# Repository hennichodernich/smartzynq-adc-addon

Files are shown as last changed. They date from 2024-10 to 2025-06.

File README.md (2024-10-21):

# smartzynq-adc-addon
KiCad files for the SmartZynq ADC addon board

*Make sure to reconfigure VCCIO on the SmartZynq to 2.5V!*

Licensed under CERN-OHL-W v2

## Hardware build

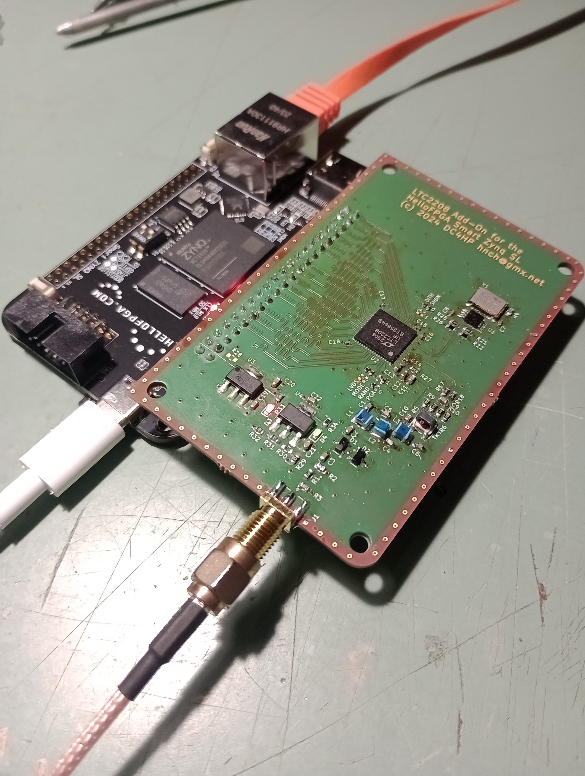
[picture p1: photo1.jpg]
The addon board mounted on the FPGA board


This board is supposed to be mounted on a HelloFPGA Smart Zynq SL FPGA board such as the one that can be purchased [here](https://aliexpress.com/item/1005006384235496.html).

It can be nicely mounted in an enclosure such as [this one](https://aliexpress.com/item/1005007125132369.html):

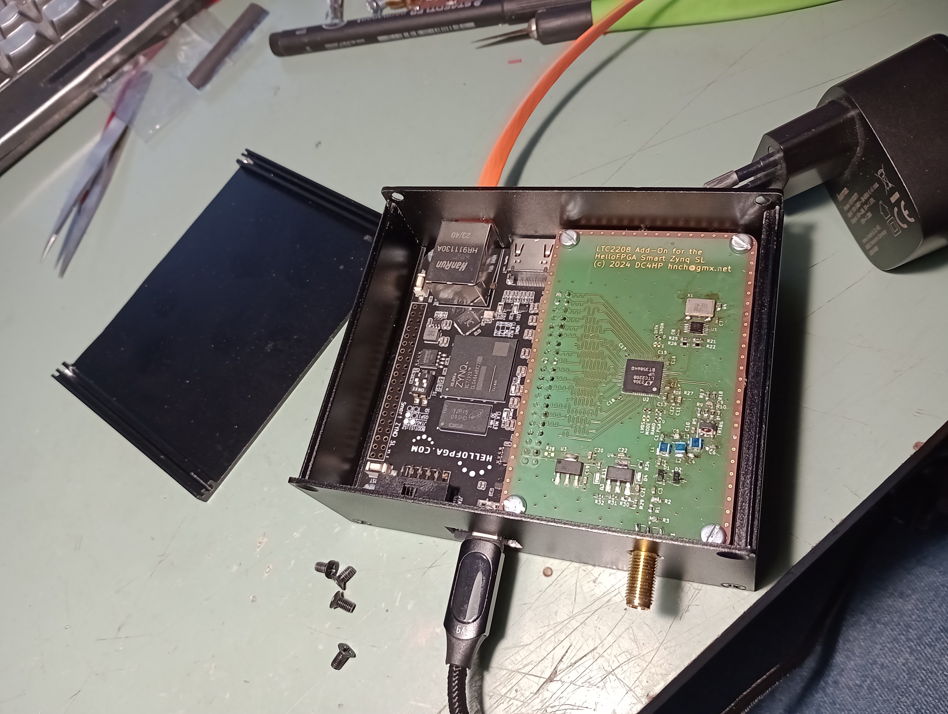
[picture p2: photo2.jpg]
Board stack mounted in enclosure


## Receive performance

The receive performance of the [sdr_receiver_ft8_122_88 project](https://github.com/hennichodernich/hellofpga-smartzynq-notes/tree/main/projects/sdr_receiver_ft8_122_88) is really good (on 22m EFHW):

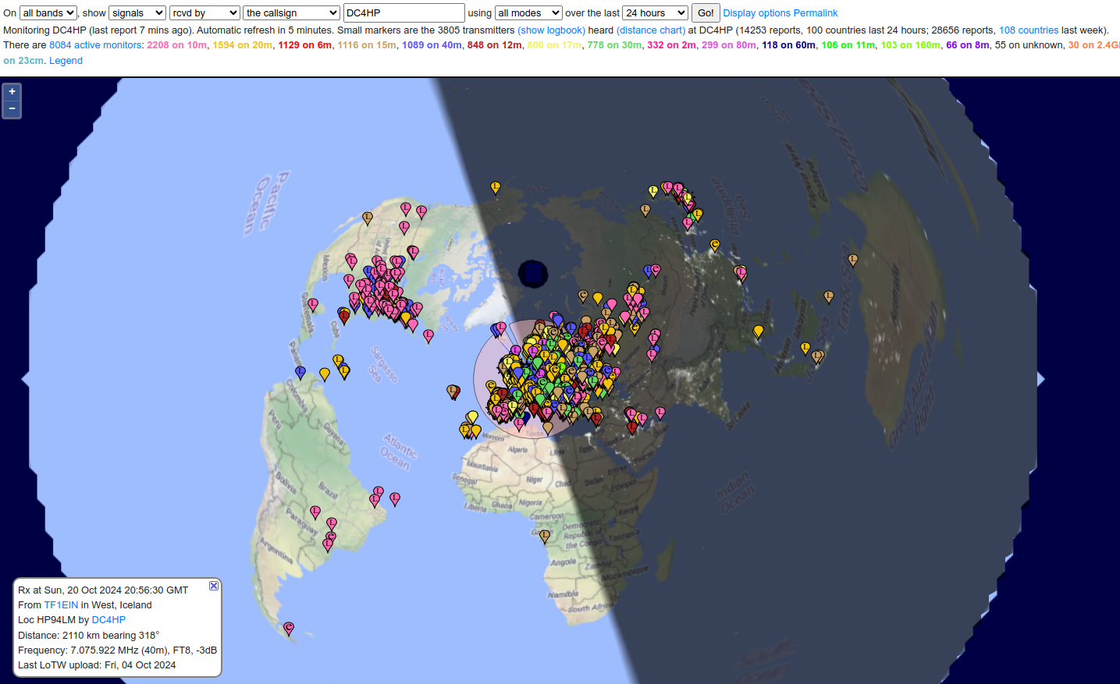
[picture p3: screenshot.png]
PSK Reporter screenshot


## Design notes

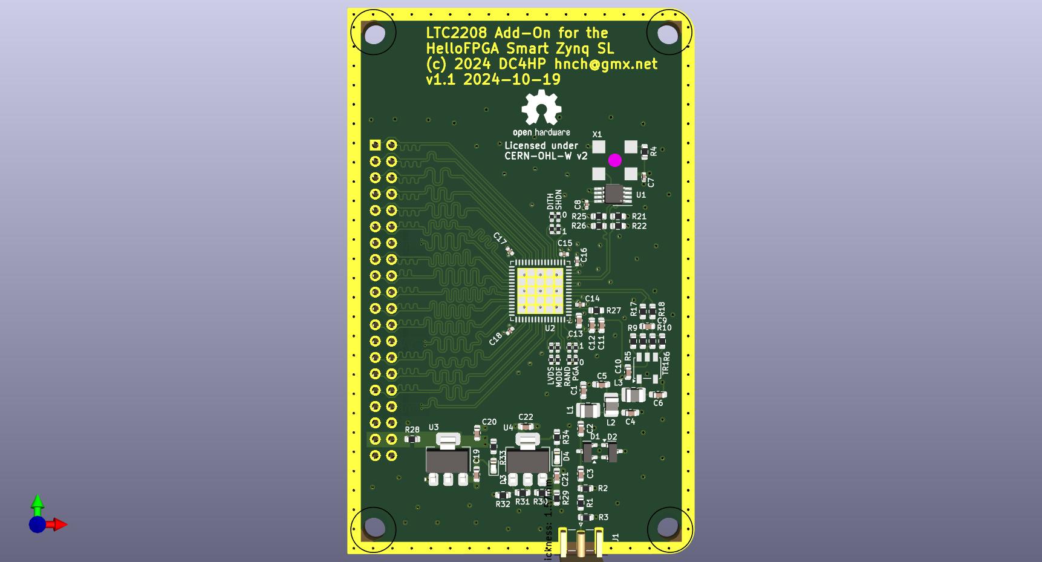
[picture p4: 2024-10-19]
kicad/ltc2208-adc.jpg

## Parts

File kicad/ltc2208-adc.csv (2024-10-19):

Reference | Value | Datasheet | Footprint | Qty | DNP
C1,C6 | 120p | ~ | hnch:C_0603_0402_HandSolder_Combo | 2
C2,C3 | 1u | ~ | Capacitor_SMD:C_0603_1608Metric | 2
C4,C5 | 220p | ~ | hnch:C_0603_0402_HandSolder_Combo | 2
C7,C8,C14,C15,C16,C17,C18 | 100n | ~ | Capacitor_SMD:C_0402_1005Metric | 7
C9 | 4.7p | ~ | Capacitor_SMD:C_0603_1608Metric | 1
C10,C11 | 10n | ~ | Capacitor_SMD:C_0603_1608Metric | 2
C12,C13,C19,C20,C21,C22 | 2.2u | ~ | Capacitor_SMD:C_0603_1608Metric | 6
D1,D2 | BAV99 | https://assets.nexperia.com/documents/data-sheet/BAV99_SER.pdf | Package_TO_SOT_SMD:SOT-23 | 2
D3,D4 | LED | ~ | LED_SMD:LED_0603_1608Metric | 2
J1 | Conn_Coaxial | ~ | Connector_Coaxial:SMA_Samtec_SMA-J-P-H-ST-EM1_EdgeMount | 1
J2 | Conn_02x20_Odd_Even | ~ | Connector_PinSocket_2.54mm:PinSocket_2x20_P2.54mm_Vertical | 1
L1,L2,L3 | 390nH | ~ | hnch:L_1008_0805_0603_HandSolder_Combo | 3
R1 | 5.1 | ~ | Resistor_SMD:R_0603_1608Metric | 1
R2,R3 | 1k | ~ | Resistor_SMD:R_0603_1608Metric | 2
R4,R7,R12,R13,R16,R20,R23 | 4.7k | ~ | -- verschiedene Werte -- | 7
R5,R6,R17,R18 | 10 | ~ | Resistor_SMD:R_0603_1608Metric | 4
R8,R11,R14,R15,R19,R24,R28,R30 | np | ~ | -- verschiedene Werte -- | 8
R9,R10 | 33.2 | ~ | Resistor_SMD:R_0603_1608Metric | 2
R21,R25 | 130 | ~ | Resistor_SMD:R_0603_1608Metric | 2
R22,R26 | 83 | ~ | Resistor_SMD:R_0603_1608Metric | 2
R27 | 100 | ~ | Resistor_SMD:R_0603_1608Metric | 1
R29 | 0 | ~ | Resistor_SMD:R_0603_1608Metric | 1
R31,R32 | 121 | ~ | Resistor_SMD:R_0603_1608Metric | 2
R33,R34 | 470 | ~ | Resistor_SMD:R_0603_1608Metric | 2
TR1 | ETC4-1-2 | https://cdn.macom.com/datasheets/ETC4-1-2-TR.pdf | Transformer_SMD:Transformer_MACOM_SM-22 | 1
U1 | SN65EPT22 | https://www.ti.com/lit/ds/symlink/sn65ept22.pdf | Package_SO:VSSOP-8_3.0x3.0mm_P0.65mm | 1
U2 | LTC2208 | https://www.analog.com/media/en/technical-documentation/data-sheets/2208fb.pdf | Package_DFN_QFN:QFN-64-1EP_9x9mm_P0.5mm_EP7.15x7.15mm | 1
U3 | LT1117-3.3 | https://www.analog.com/media/en/technical-documentation/data-sheets/1117fd.pdf | Package_TO_SOT_SMD:SOT-223-3_TabPin2 | 1
U4 | LT1117-ADJ | https://www.analog.com/media/en/technical-documentation/data-sheets/1117fd.pdf | Package_TO_SOT_SMD:SOT-223-3_TabPin2 | 1
X1 | 122.88 MHz | http://cdn-reichelt.de/documents/datenblatt/B400/XO91.pdf | Oscillator:Oscillator_SMD_EuroQuartz_XO91-4Pin_7.0x5.0mm | 1

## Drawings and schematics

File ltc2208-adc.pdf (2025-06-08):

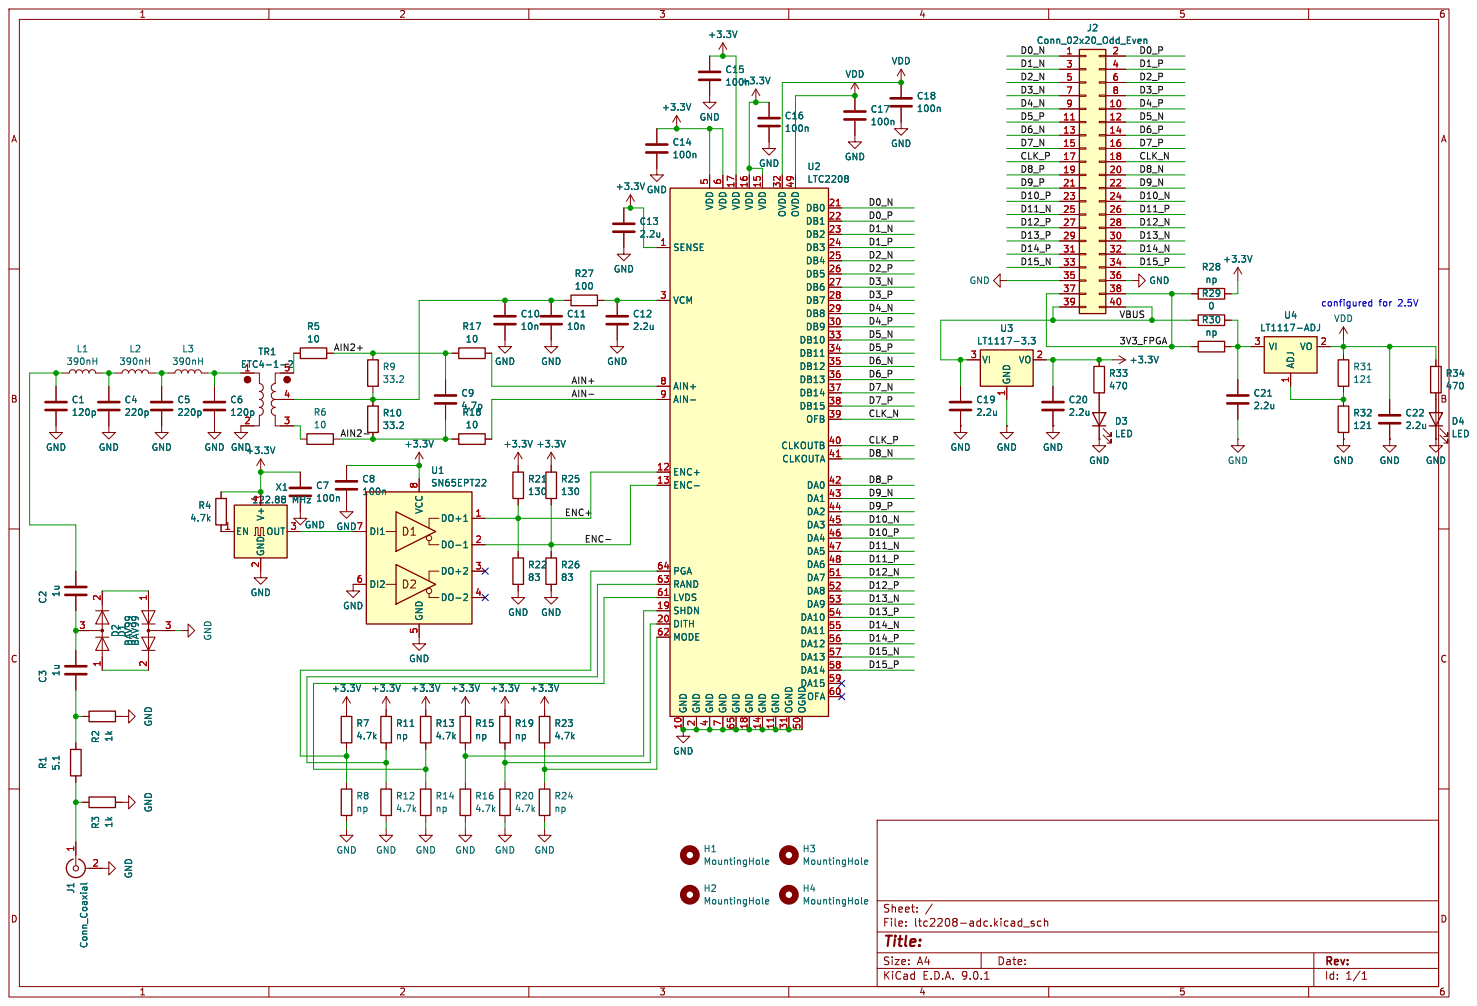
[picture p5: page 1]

7 VDD 16 VDD 15 GND 14 GND 11 OFB 39 SENSE 1 VCM 3 AIN+ 8 AIN- 9 ENC+ 12 ENC- 13 PGA 64 RAND 63 SHDN 19 DITH 20 MODE 62 VDD

6 VDD 17 GND 65 GND 18 OVDD 32 OGND 31 OVDD 49 OGND 50 DB0 21 DB1 22 DB2 23 DB3 24 DB4 25 DB5 26 DB6 27 DB7 28 DB8 29 DB9 30 DB10 33 DB11 34 DB12 35 DB13 36 DB14 37 DB15 38 CLKOUTB 40 CLKOUTA 41 DA0 42 DA1 43 DA2 44 DA3 45 DA4 46 DA5 47 DA6 48 DA7 51 DA8 52 DA9 53 DA10 54 DA11 55 DA12 56 DA13 57 DA14 58 DA15 59 OFA 60 GND

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

5 DO+1 1 DO-1 2 DO+2 3 DO-2 4 U1SN65EPT22 +3.3V C13

2 R31k J1 Conn_Coaxial 1
Id: 1/1 Title: File: ltc2208-adc.kicad_sch Sheet: / C31u

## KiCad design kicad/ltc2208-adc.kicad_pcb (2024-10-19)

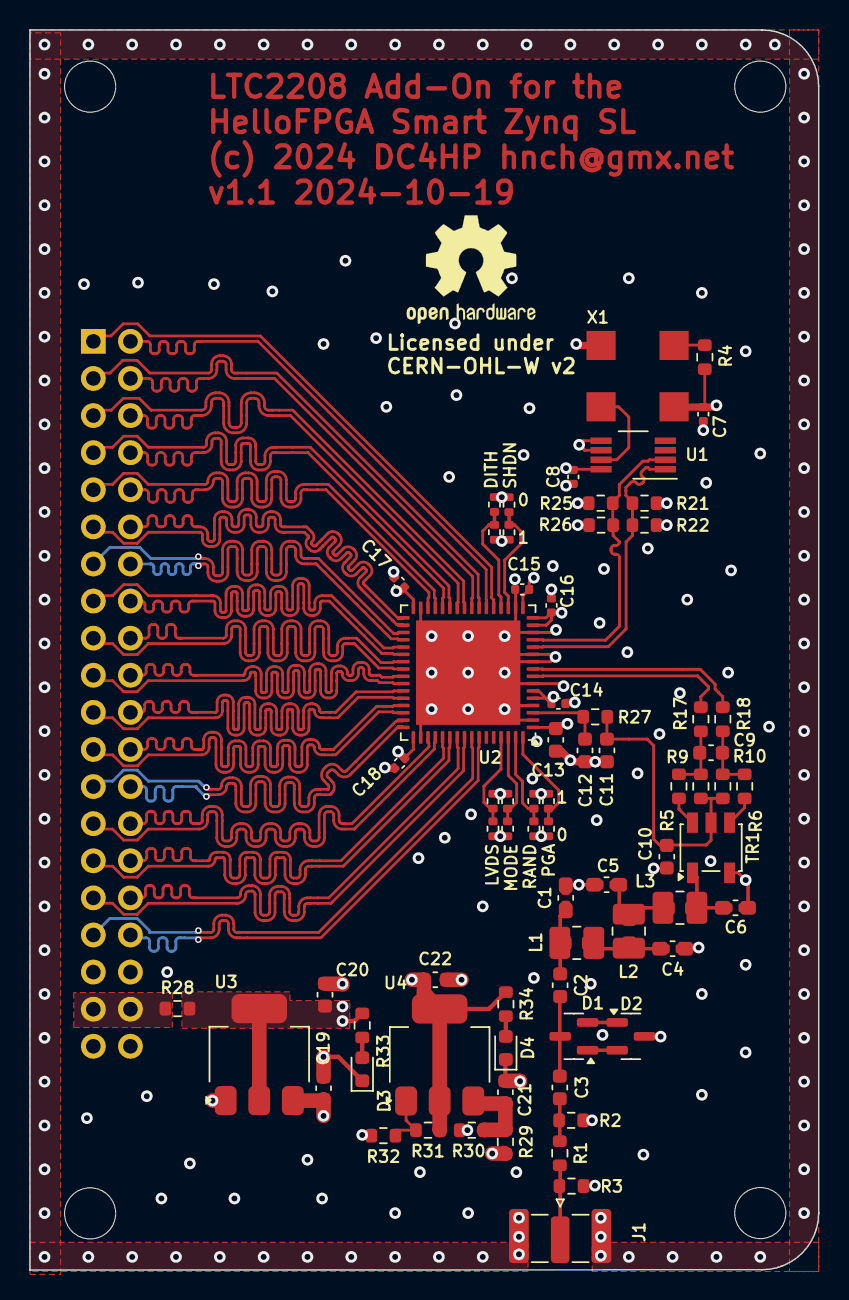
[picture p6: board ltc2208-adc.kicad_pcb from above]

Board: 4 copper layers, 54.0 x 84.9 mm, 75 parts (1 on the bottom side), 70 nets.

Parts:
C1, C4, C5, C6: C; C_0603_0402_HandSolder_Combo
C2, C3: 1u; C_0603_1608Metric
C7, C8, C14, C15, C16, C17, C18: 100n; C_0402_1005Metric
C9: 4.7p; C_0603_1608Metric
C10, C11: 10n; C_0603_1608Metric
C12, C13, C19, C20, C21, C22: 2.2u; C_0603_1608Metric
D1, D2: BAV99; SOT-23
D3, D4: LED; LED_0603_1608Metric
H1, H2, H3, H4: MountingHole; MountingHole_3.5mm
J1: Conn_Coaxial; SMA_Samtec_SMA-J-P-H-ST-EM1_EdgeMount
J2: Conn_02x20_Odd_Even; PinSocket_2x20_P2.54mm_Vertical
L1, L2, L3: L; L_1008_0805_0603_HandSolder_Combo
R1: 5.1; R_0603_1608Metric
R2, R3: 1k; R_0603_1608Metric
R4: 4.7k; R_0603_1608Metric
R5, R6, R17, R18: 10; R_0603_1608Metric
R7, R8, R11, R12, R13, R14, R15, R16, R19, R20, R23, R24: 4.7k; R_0402_1005Metric
R9, R10: 33.2; R_0603_1608Metric
R21, R25: 130; R_0603_1608Metric
R22, R26: 83; R_0603_1608Metric
R27: 100; R_0603_1608Metric
R28, R29, R30: 0; R_0603_1608Metric
R31, R32: R; R_0603_1608Metric
R33, R34: 470; R_0603_1608Metric
TR1: ETC4-1-2; Transformer_MACOM_SM-22
U1: SN65EPT22; VSSOP-8_3.0x3.0mm_P0.65mm
U2: LTC2208; QFN-64-1EP_9x9mm_P0.5mm_EP7.15x7.15mm
U3: LT1117-3.3; SOT-223-3_TabPin2
U4: LT1117-ADJ; SOT-223-3_TabPin2
X1: XO91; Oscillator_SMD_EuroQuartz_XO91-4Pin_7.0x5.0mm

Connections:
+3.3V: C7.1, C8.1, C13.1, C14.1, C15.1, C16.1, C20.1, R4.1, R7.1, R11.1, R13.1, R15.1, R19.1, R21.1, R23.1, R25.1, R28.2, R33.1, U1.8 (VCC), U2.1 (SENSE), U2.5 (VDD), U2.6 (VDD), U2.15 (VDD), U2.16 (VDD), U2.17 (VDD), U3.2 (VO), X1.4 (V+)
/3V3_FPGA: J2.37, J2.38, R28.1, R30.1
/AIN2+: C9.1, R5.2, R9.1, R17.1
/AIN2-: C9.2, R6.2, R10.2, R18.1
/AIN+: R17.2, U2.8 (AIN+)
/AIN-: R18.2, U2.9 (AIN-)
/CLK_N: J2.18, U2.39 (OFB)
/CLK_P: J2.17, U2.40 (CLKOUTB)
/D0_N: J2.1, U2.21 (DB0)
/D0_P: J2.2, U2.22 (DB1)
/D1_N: J2.3, U2.23 (DB2)
/D1_P: J2.4, U2.24 (DB3)
/D2_N: J2.5, U2.25 (DB4)
/D2_P: J2.6, U2.26 (DB5)
/D3_N: J2.7, U2.27 (DB6)
/D3_P: J2.8, U2.28 (DB7)
/D4_N: J2.9, U2.29 (DB8)
/D4_P: J2.10, U2.30 (DB9)
/D5_N: J2.12, U2.33 (DB10)
/D5_P: J2.11, U2.34 (DB11)
/D6_N: J2.13, U2.35 (DB12)
/D6_P: J2.14, U2.36 (DB13)
/D7_N: J2.15, U2.37 (DB14)
/D7_P: J2.16, U2.38 (DB15)
/D8_N: J2.20, U2.41 (CLKOUTA)
/D8_P: J2.19, U2.42 (DA0)
/D9_N: J2.22, U2.43 (DA1)
/D9_P: J2.21, U2.44 (DA2)
/D10_N: J2.24, U2.45 (DA3)
/D10_P: J2.23, U2.46 (DA4)
/D11_N: J2.25, U2.47 (DA5)
/D11_P: J2.26, U2.48 (DA6)
/D12_N: J2.28, U2.51 (DA7)
/D12_P: J2.27, U2.52 (DA8)
/D13_N: J2.30, U2.53 (DA9)
/D13_P: J2.29, U2.54 (DA10)
/D14_N: J2.32, U2.55 (DA11)
/D14_P: J2.31, U2.56 (DA12)
/D15_N: J2.33, U2.57 (DA13)
/D15_P: J2.34, U2.58 (DA14)
/ENC+: R21.2, R22.1, U1.1 (DO+1), U2.12 (ENC+)
/ENC-: R25.2, R26.1, U1.2 (DO-1), U2.13 (ENC-)
/VBUS: C19.1, J2.39, J2.40, R29.1, U3.3 (VI)
GND: C1.2, C4.2, C5.2, C6.2, C7.2, C8.2, C10.2, C11.2, C12.2, C13.2, C14.2, C15.2, C16.2, C17.2, C18.2, C19.2, C20.2, C21.2, C22.2, D2.3 (K), D3.1 (K), D4.1 (K), J1.2 (Ext), J2.35, J2.36, R2.2, R3.2, R8.2, R12.2, R14.2, R16.2, R20.2, R22.2, R24.2, R26.2, R32.2, TR1.2, U1.5 (GND), U1.6 (DI2), U2.2 (GND), U2.4 (GND), U2.7 (GND), U2.10 (GND), U2.11 (GND), U2.14 (GND), U2.18 (GND), U2.31 (OGND), U2.50 (OGND), U2.65 (GND), U3.1 (GND), X1.2 (GND)
unnamed: C1.1, C2.1, L1.1
unnamed: C2.2, C3.1, D1.3 (K)
unnamed: C3.2, R1.1, R2.1
unnamed: C4.1, L1.2, L2.1
unnamed: C5.1, L2.2, L3.1
unnamed: C6.1, L3.2, TR1.1
unnamed: C10.1, C11.1, R9.2, R10.1, R27.1, TR1.4
unnamed: D1.2 (A), D2.1 (K)
unnamed: D1.1 (K), D2.2 (A)
unnamed: D3.2 (A), R33.2
unnamed: D4.2 (A), R34.2
unnamed: J1.1 (In), R1.2, R3.1
unnamed: R5.1, TR1.5
unnamed: R6.1, TR1.3
unnamed: U1.7 (DI1), X1.3 (OUT)
unnamed: R19.2, R20.1, U2.20 (DITH)
unnamed: R13.2, R14.1, U2.61 (LVDS)
unnamed: R23.2, R24.1, U2.62 (MODE)
unnamed: R7.2, R8.1, U2.64 (PGA)
unnamed: R11.2, R12.1, U2.63 (RAND)
unnamed: R15.2, R16.1, U2.19 (SHDN)
unnamed: C12.1, R27.2, U2.3 (VCM)
unnamed: R31.2, R32.1, U4.1 (ADJ)
unnamed: C21.1, R29.2, R30.2, U4.3 (VI)
unnamed: R4.2, X1.1 (EN)
VDD: C17.1, C18.1, C22.1, R31.1, R34.1, U2.32 (OVDD), U2.49 (OVDD), U4.2 (VO)

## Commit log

2024-10-19 Clarified VCCIO issue
    [ltc2208-adc.csv, ltc2208-adc.kicad_sch]
2024-10-21 Moved files into kicad subdir
    [ltc2208-adc.csv, ltc2208-adc.kicad_pcb, ltc2208-adc.kicad_sch]
2025-06-08 Added schematic as PDF

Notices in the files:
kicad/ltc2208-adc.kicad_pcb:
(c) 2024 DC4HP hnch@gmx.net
